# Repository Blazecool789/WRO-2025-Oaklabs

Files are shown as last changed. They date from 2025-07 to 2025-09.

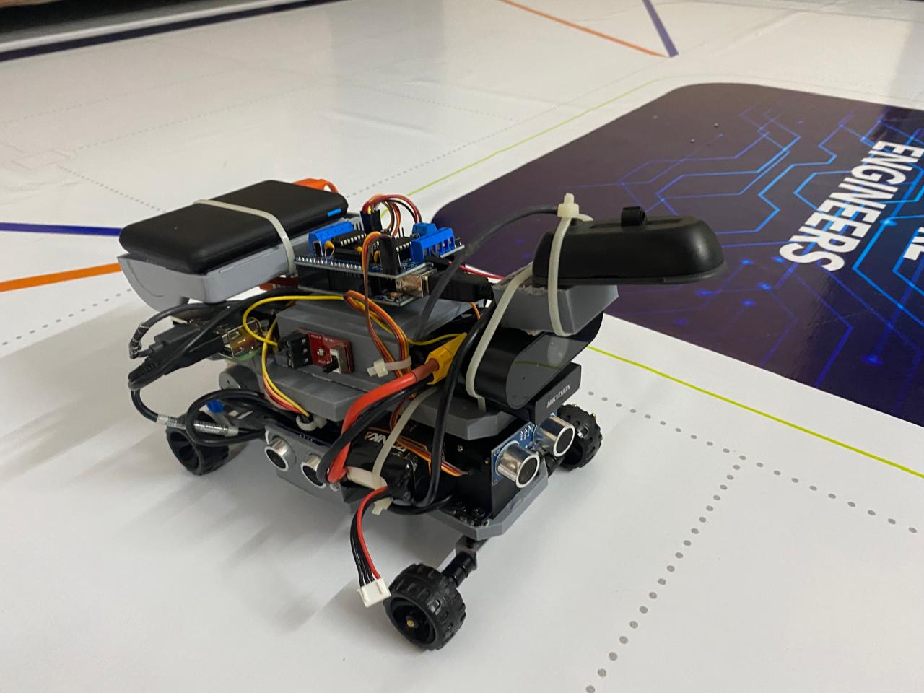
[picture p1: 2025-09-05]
Bot Photos/Top Side View.jpg

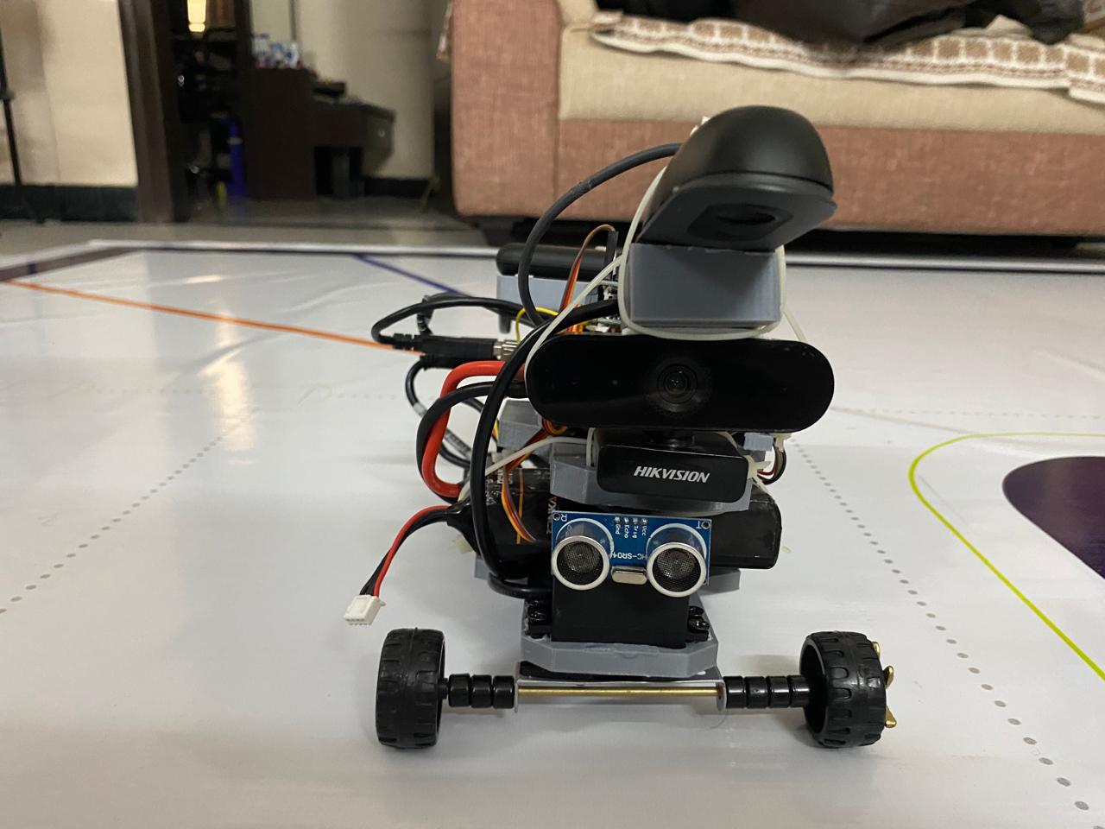
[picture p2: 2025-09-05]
Bot Photos/Front View.jpg

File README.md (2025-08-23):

# Oak-Labs

This repository contains the work of Team Oaklabs, developed for the WRO 2025 Future Engineers competition. Our robot combines simplicity with advanced technical systems to ensure efficiency, reliability, and adaptability across all phases of the challenge.

### Members:
 - Supratiik Koppuravuri

 - Aneesh Kulkarni

 - Krishna Hanumanthu

## Project/bot description :

Our robot is designed around a distributed control system that uses two microcontrollers: an Arduino Uno and a Raspberry Pi 5.

The Arduino Uno handles real-time actuation, low-latency sensor processing, and precise motor control.

The Raspberry Pi 5 performs high-level decision-making, camera-based vision processing, and computationally intensive tasks.

## Table of contents :

Team-photos : Photos of each team member (formal & informal)

Bot-photos : Multiple views of the robot (front, back, left, right, top, bottom)

Diagrams and schemes : Visual representations of system architecture, wiring, and component interconnections

Materials and components : Detailed list of all hardware and electronics used

3D models : CAD designs and animations of the robot build

Reference documents : Reports/manuals covering design decisions and logistics

TeamCode : Complete codebase with explanations for each competition phase

Videos : Demonstration of the robot performing different tasks

## Introduction

Team Oaklabs proudly presents its robot for the World Robot Olympiad 2025 (Future Engineers).

Our design philosophy emphasizes efficiency, precision, and modularity. By distributing responsibilities between the Arduino and Raspberry Pi, the robot executes movements with speed while simultaneously processing complex vision-based tasks.

Highlights of our approach:

Distributed architecture: separates time-critical motor control from computationally heavy tasks.

Sensor fusion: combines ultrasonic data with camera vision for robust navigation.

Adaptive behavior: the robot dynamically switches strategies between obstacle navigation, line-following, and parallel parking.

Deterministic communication protocol: ensures that commands from the Raspberry Pi to the Arduino translate into predictable actions.

Modularity: components can be easily replaced or upgraded, making the system flexible and competition-ready.

By balancing advanced algorithms with practical engineering, Oaklabs has built a robot capable of tackling every stage of the competition with speed, consistency, and adaptability.

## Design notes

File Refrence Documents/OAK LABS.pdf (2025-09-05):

# OAK LABS

# Team No. 1121 Aneesh, Supratiik, & Krishna

# Future engineer’s JOURNAL

# The Team

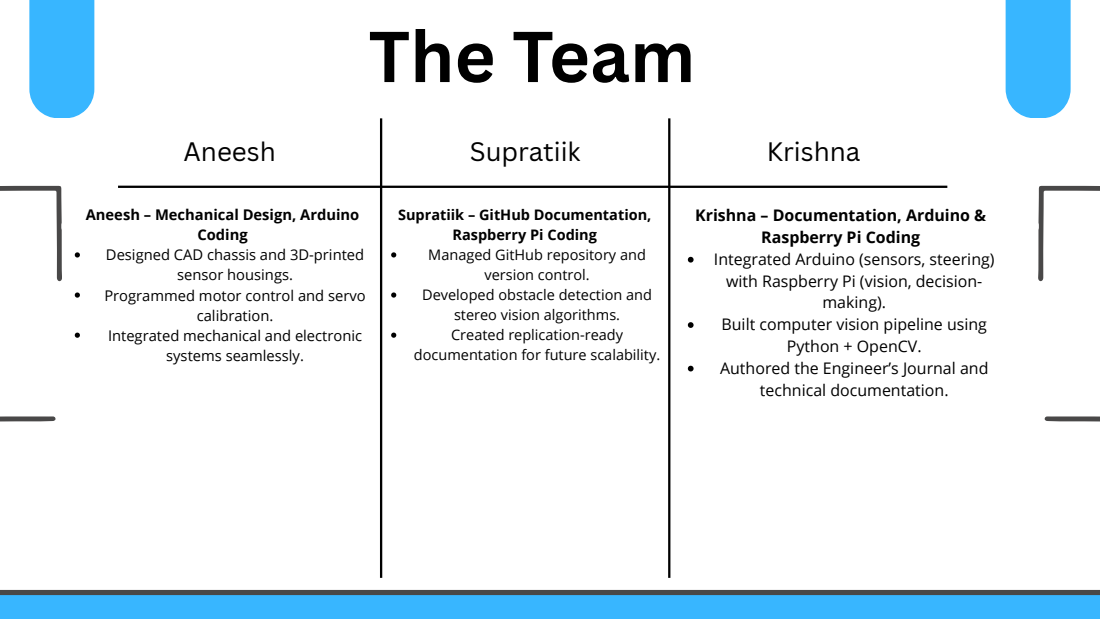
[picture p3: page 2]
Aneesh; Supratiik; Krishna; making).; Python + OpenCV.; Coding; sensor housings.; calibration.

Aneesh – Mechanical Design, Arduino

Supratiik – GitHub Documentation,
Raspberry Pi Coding
Managed GitHub repository and
version control.

Krishna – Documentation, Arduino &

Integrated Arduino (sensors, steering)
with Raspberry Pi (vision, decision-

Designed CAD chassis and 3D-printed

Programmed motor control and servo

Developed obstacle detection and
stereo vision algorithms.
Created replication-ready
documentation for future scalability.

Built computer vision pipeline using

Integrated mechanical and electronic
systems seamlessly.

Authored the Engineer’s Journal and
technical documentation.

# TABLE OF CONTENTS

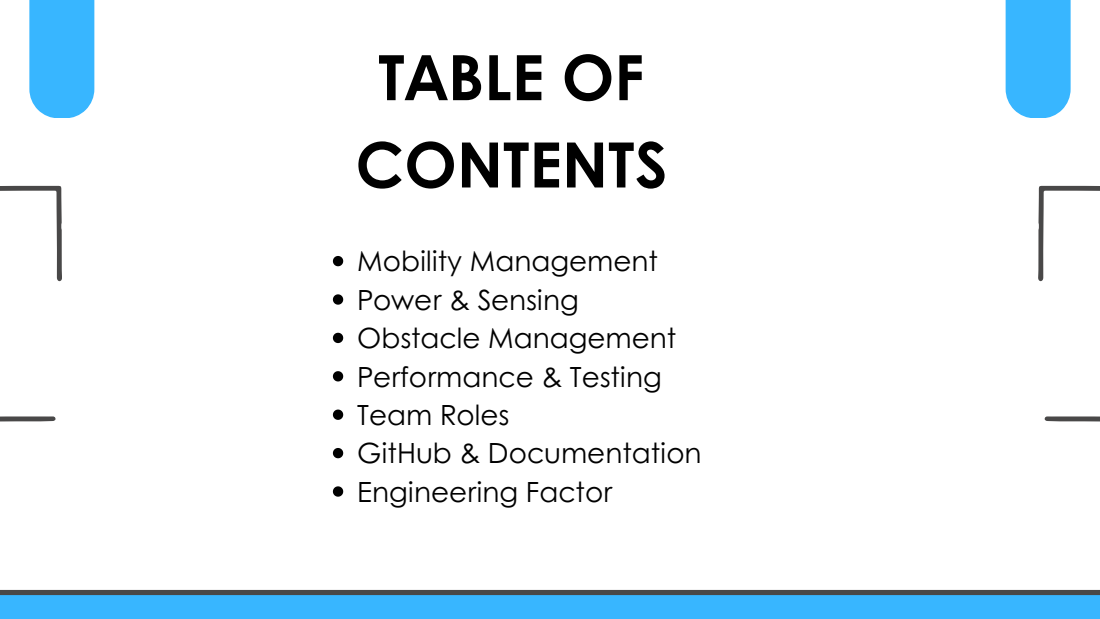
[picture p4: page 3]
Mobility Management Power & Sensing Obstacle Management Performance & Testing Team Roles GitHub & Documentation Engineering Factor

# 1. Mobility Management

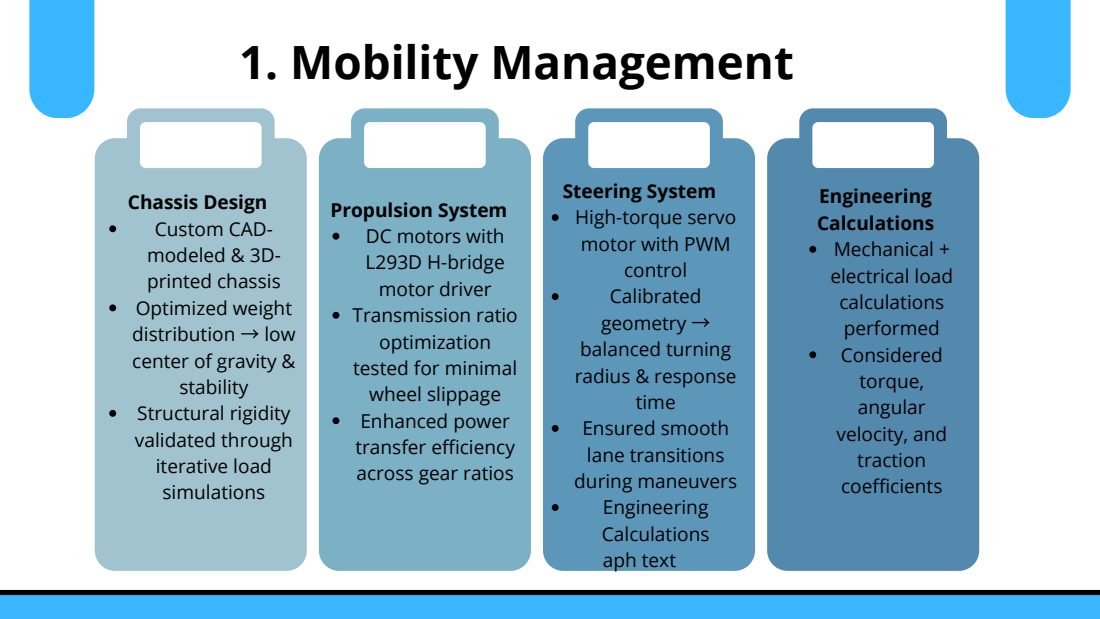
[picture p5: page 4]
Engineering Calculations Mechanical + electrical load calculations performed Considered torque, angular velocity, and traction coefficients

Steering System
High-torque servo
motor with PWM
control
Calibrated
geometry →
balanced turning
radius & response
time
Ensured smooth
lane transitions
during maneuvers
Engineering
Calculations
aph text

Chassis Design
Custom CAD-
modeled & 3D-
printed chassis
Optimized weight
distribution → low
center of gravity &
stability
Structural rigidity
validated through
iterative load
simulations

Propulsion System
DC motors with
L293D H-bridge
motor driver
Transmission ratio
optimization
tested for minimal
wheel slippage
Enhanced power
transfer efficiency
across gear ratios

# 2.POWER & SENSE MANAGMENT

## Power & Sense Management Power Architecture

Dual-source: Li-ion battery for Arduino, power bank for Raspberry Pi. Energy audit ensured stable voltage and prevented brownouts.

## Perception System

Stereo vision with dual webcams for lane detection & sign recognition. Depth estimation improved accuracy in feature extraction.

## Sensor Fusion

HC-SR04 ultrasonic sensor for obstacle ranging. Combined with vision data for reliable detection.

## Wiring & Stability

Structured wiring plan + Bill of Materials (BOM). Capacitor-based decoupling reduced noise and stabilized signals.

# OBSTACLE MANAGEMENT

Vision-Based Detection
Python + OpenCV pipeline for obstacle segmentation
NumPy computations enabled real-time matrix operations Decision-Making Algorithm
Flowchart-based logic converted sensor data into avoidance maneuvers Fusion of vision + ultrasonic inputs for reliable decisions
Safety & Reliability
Failsafe stop protocol triggered on conflicting sensor signals
Priority given to collision prevention over lane-following Ultrasonic Integration
Arduino trigger–echo time-of-flight algorithm for precise ranging Millimeter-scale accuracy achieved during testing
Performance Validation
Avoidance maneuvers maintained lane alignment
System proven robust under multi-variable test scenarios

GitHub Utilization
Repository Structure
/software – Python and Arduino source code
/hardware – CAD models, wiring diagrams, 3D-print files
/docs – Engineer’s Journal, schematics, testing protocols, performance logs /media – Photos, annotated diagrams, demonstration videos
Version Control & Collaboration Git used with descriptive commit messages (e.g., fix, feat, tune)
Frequent commits by all team members demonstrate distributed collaboration
Ensures iterative refinement and traceability of changes
Documentation & Replication README.md includes setup instructions, architectural explanations, and replication guidelines Supports knowledge transfer for future teams

# GITHUB UTILIZATION

Engineering Factor
Custom Architecture & Modularity Integrated off-the-shelf components into a bespoke, scalable system Guided by principles of modularity and expandability
Chassis & Mechanical Design 3D-printed chassis iteratively refined, reducing weight by 20% Maintained structural rigidity while optimizing maneuverability Adjusted mechanical elements to improve transmission efficiency
Electrical & Sensor Optimization Power regulation circuits improved to mitigate instability
Sensor suite designed for maximum field-of-view for lane detection and obstacle avoidance Iterative Engineering Cycle Early prototypes addressed overweight, energy inefficiency, and imbalance
Final design achieved lightweight, reliable, and optimized autonomous platform Demonstrates analysis → prototyping → testing → refinement

# ENGINEERING FACTOR

# THANK YOU

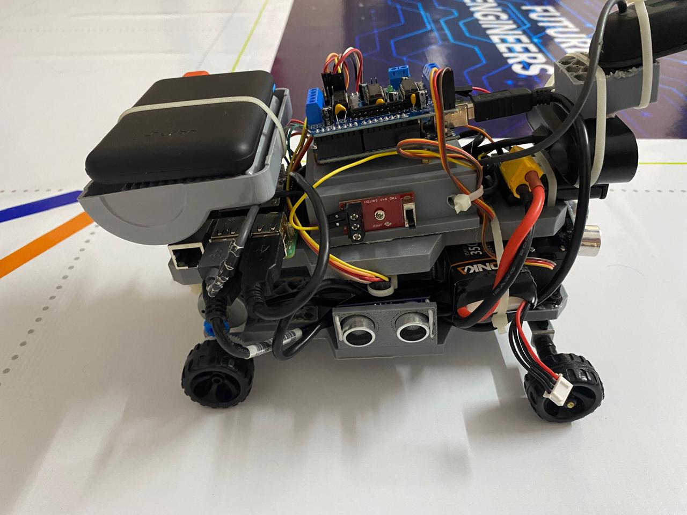
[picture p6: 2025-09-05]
Bot Photos/Side View.jpg

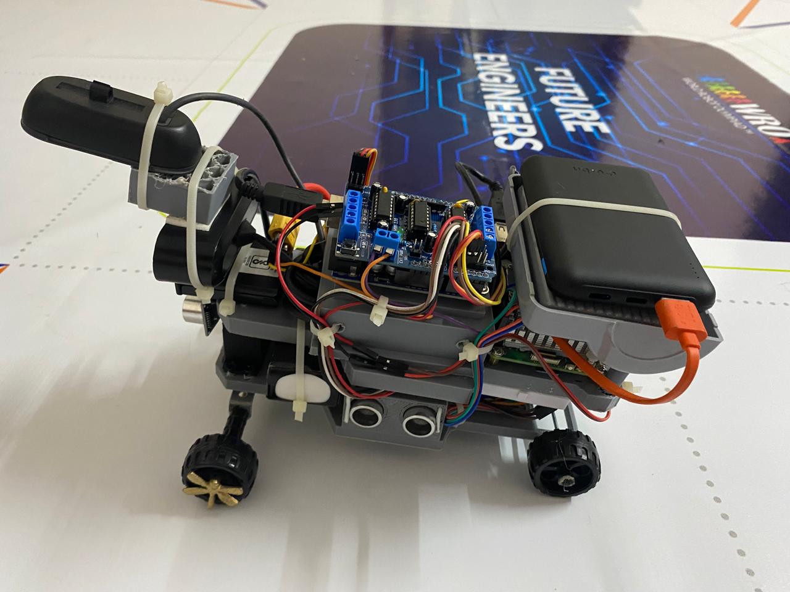
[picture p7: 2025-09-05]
Bot Photos/Other Side View.jpg

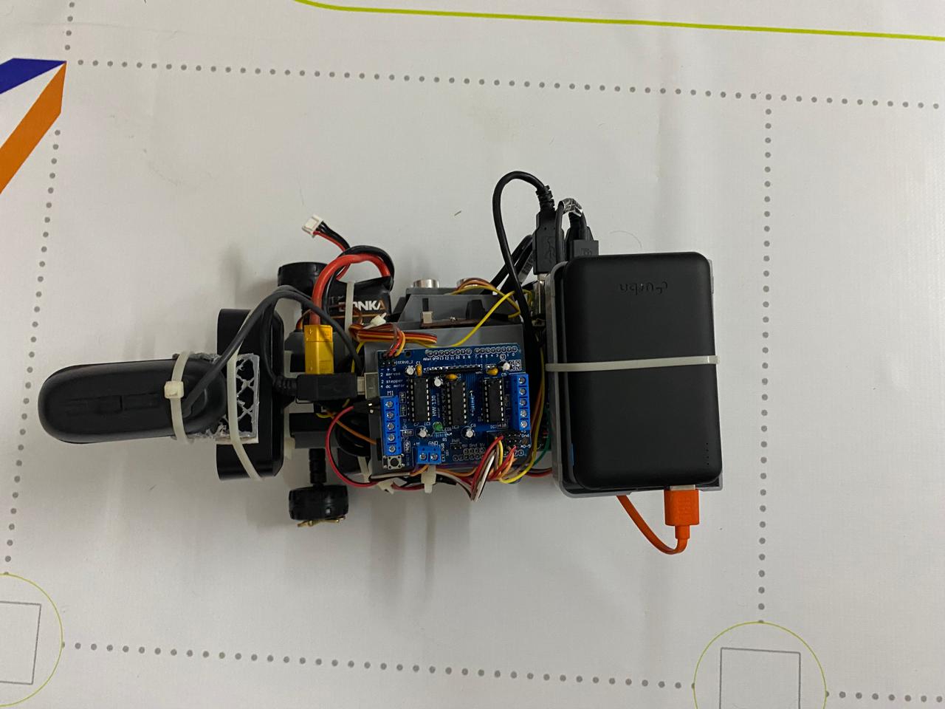
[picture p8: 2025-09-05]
Bot Photos/Top View.jpg

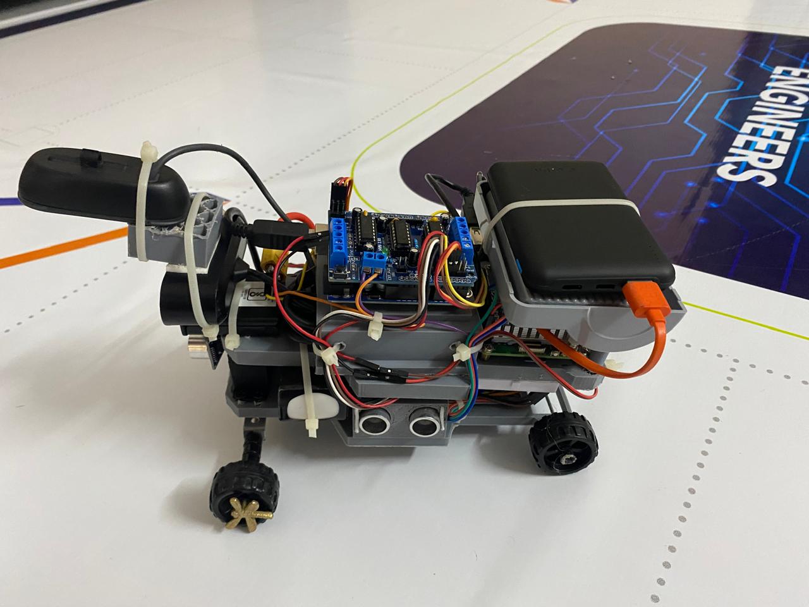
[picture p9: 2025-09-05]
Bot Photos/Top Other Side View.jpg

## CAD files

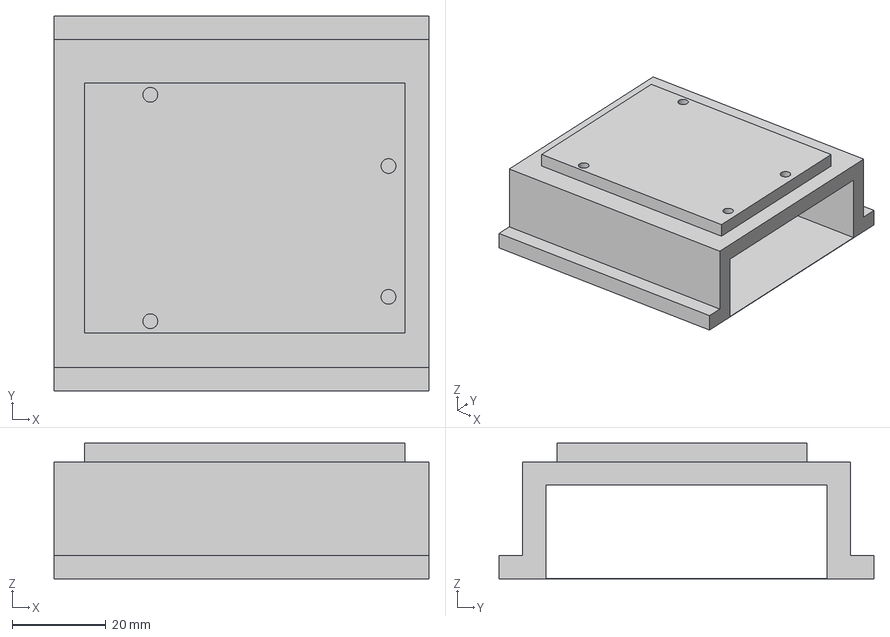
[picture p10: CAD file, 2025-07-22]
3D designs/Arduino Mount/Arduino mount v2.3mf
80.0 x 80.0 x 29.0 mm

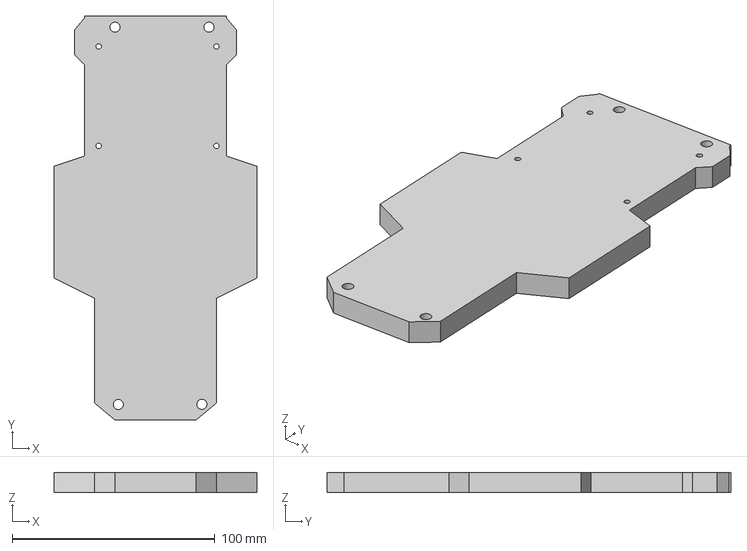
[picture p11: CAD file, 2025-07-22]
3D designs/Baseplate/Baseplate_.3mf
100.0 x 199.0 x 10.0 mm

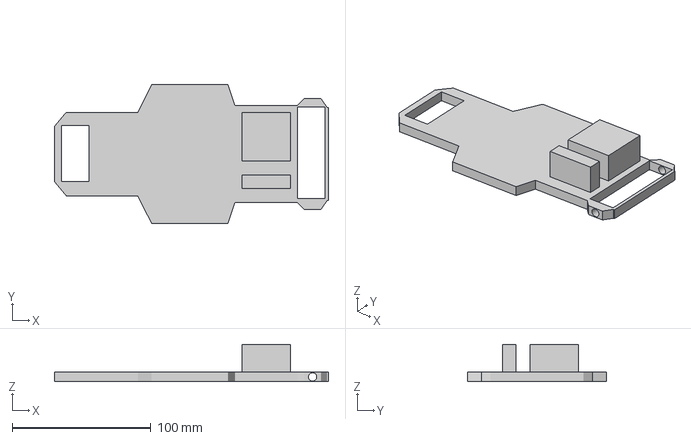
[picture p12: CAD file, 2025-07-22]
3D designs/Bottom Plate/Bottom Plate_.3mf
197.5 x 100.0 x 27.0 mm

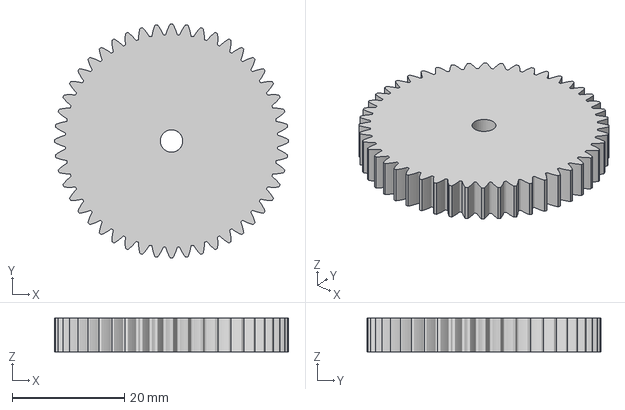
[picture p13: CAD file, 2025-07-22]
3D designs/Gear/Gears v5.3mf
41.7 x 41.7 x 6.00 mm

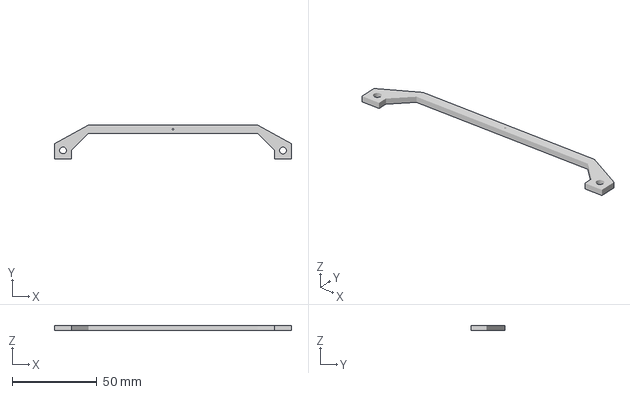
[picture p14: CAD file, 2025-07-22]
3D designs/Steering Actuator/Steering Actuator_.3mf
140.0 x 20.0 x 3.00 mm

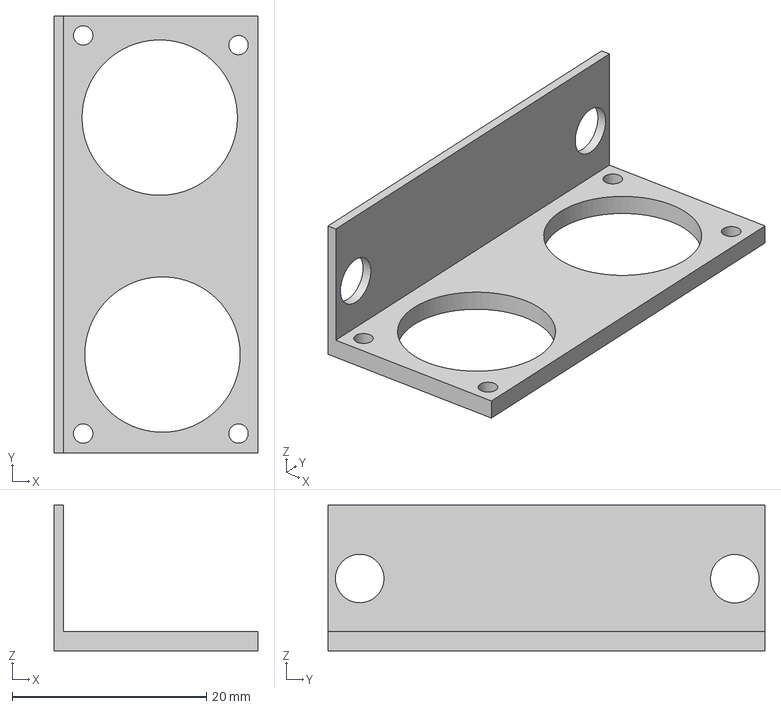
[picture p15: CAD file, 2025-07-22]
3D designs/Ultrasonic Baseplate/Ultrasonic Sensor Baseplate_.3mf
21.0 x 45.0 x 15.0 mm

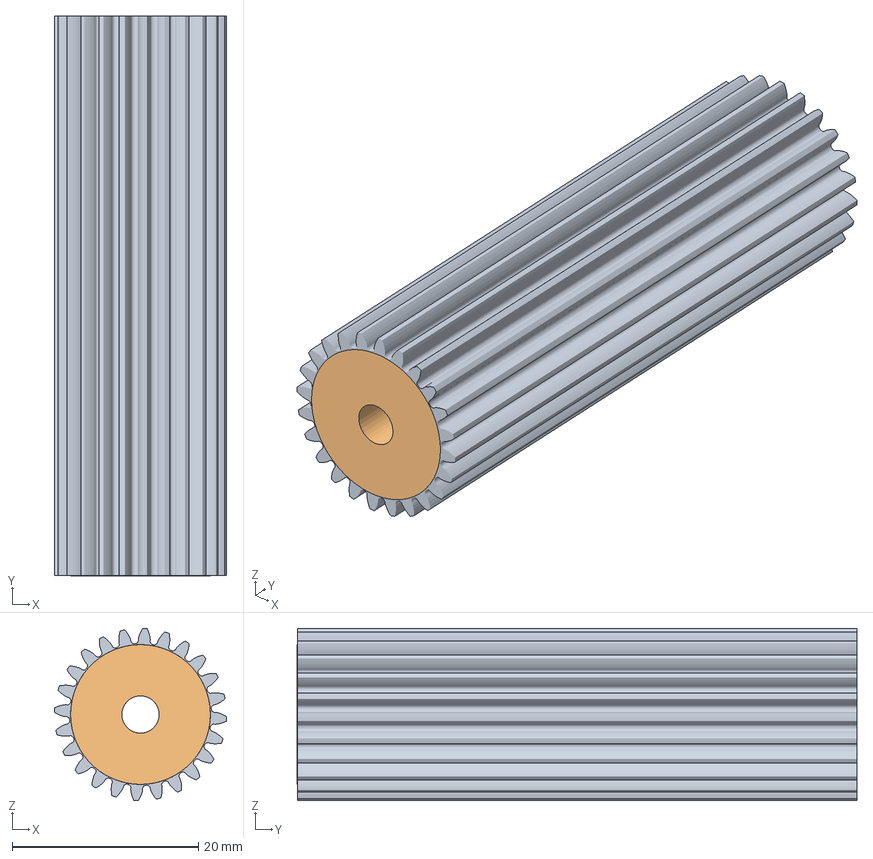
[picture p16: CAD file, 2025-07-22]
3D designs/Gear/Back Gear v3.3mf
18.5 x 60.0 x 18.5 mm

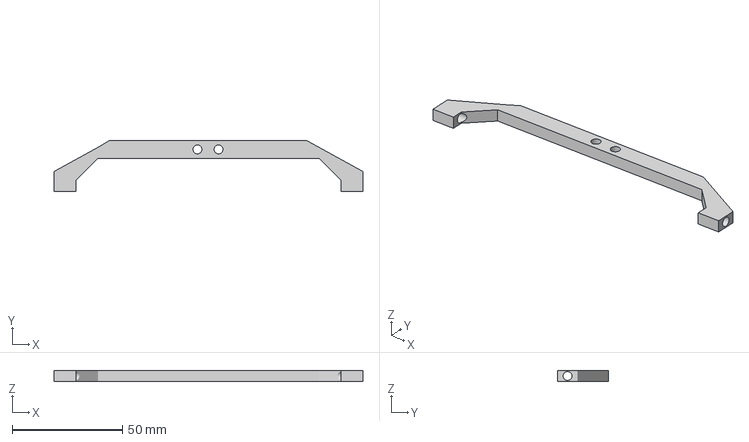
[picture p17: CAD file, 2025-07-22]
3D designs/Steering Actuator/Steering Actuator v8.3mf
140.0 x 23.0 x 5.00 mm

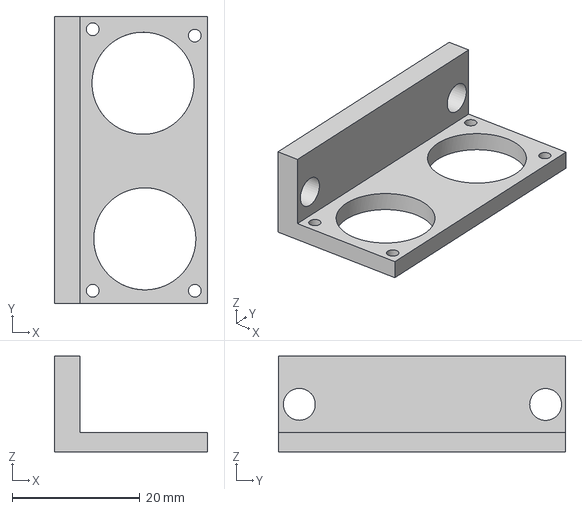
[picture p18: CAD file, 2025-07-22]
3D designs/Ultrasonic Baseplate/Ultrasonic Sensor Baseplate v4.3mf
24.0 x 45.0 x 15.0 mm

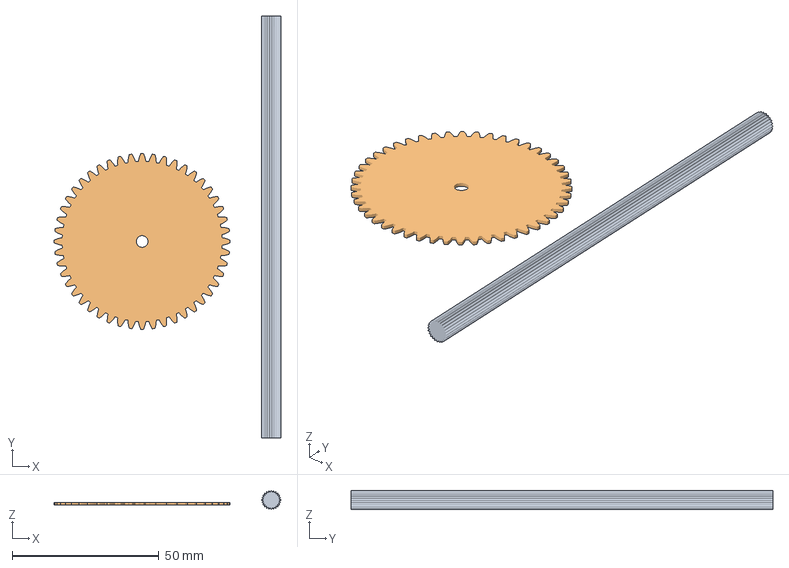
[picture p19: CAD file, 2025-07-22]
3D designs/Gear/Gears_.3mf
77.3 x 144.0 x 6.50 mm

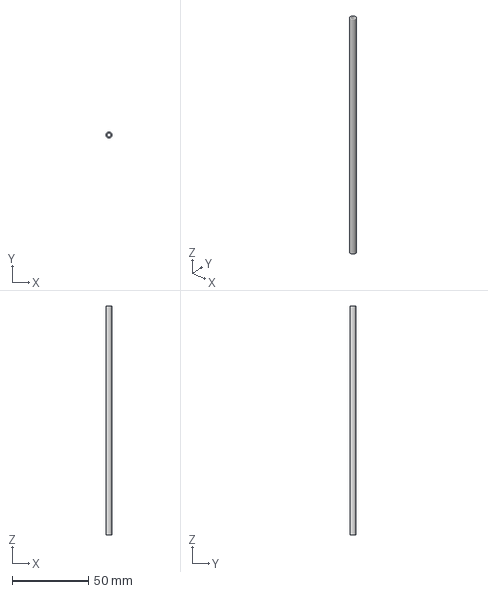
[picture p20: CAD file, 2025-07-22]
3D designs/Steering Actuator/Height Standoff v1.3mf
4.00 x 4.00 x 150.0 mm

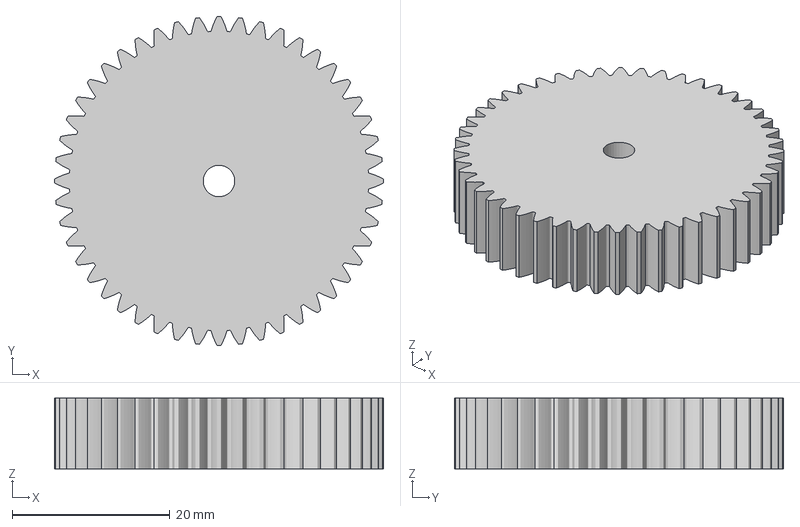
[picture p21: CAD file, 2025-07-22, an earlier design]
3D designs/Gear/Gears v4.3mf
41.7 x 41.7 x 9.00 mm

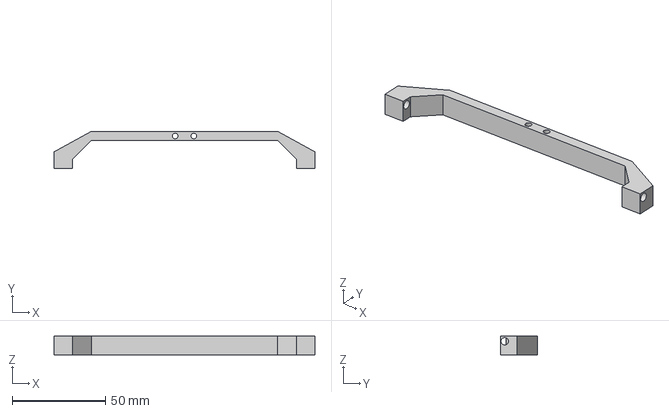
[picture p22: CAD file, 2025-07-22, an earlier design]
3D designs/Steering Actuator/Steering Actuator v5.3mf
140.0 x 20.0 x 10.0 mm

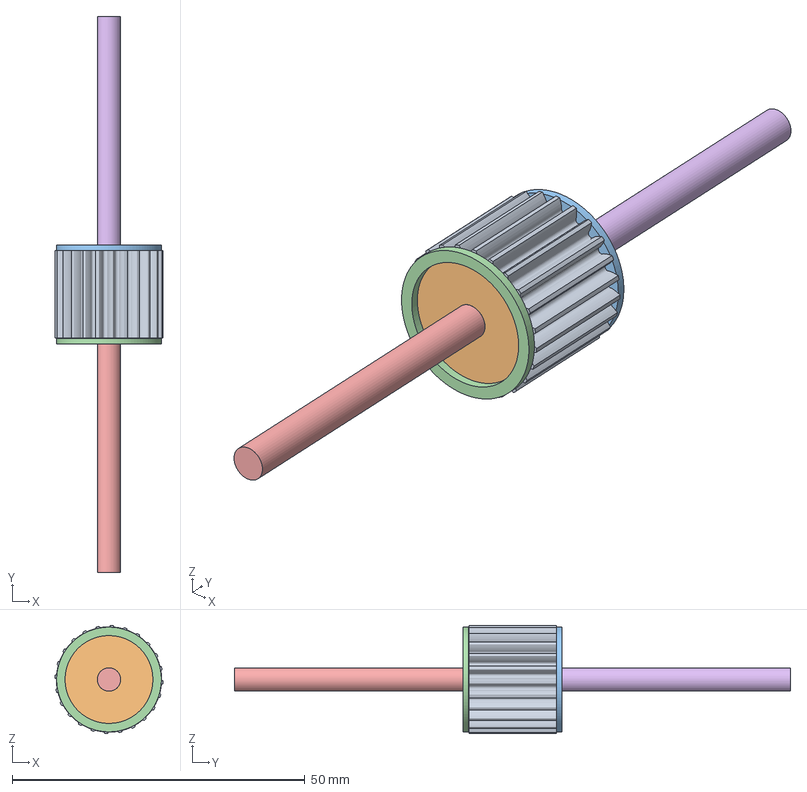
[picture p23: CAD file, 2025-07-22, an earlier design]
3D designs/Gear/Back Gear v2.3mf
18.5 x 95.0 x 18.5 mm

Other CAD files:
3D designs/Steering Actuator/Steering Actuator v6.3mf
3D designs/Gear/Back Gear v1.3mf
3D designs/Ultrasonic Baseplate/Ultrasonic Sensor Baseplate v4.f3d

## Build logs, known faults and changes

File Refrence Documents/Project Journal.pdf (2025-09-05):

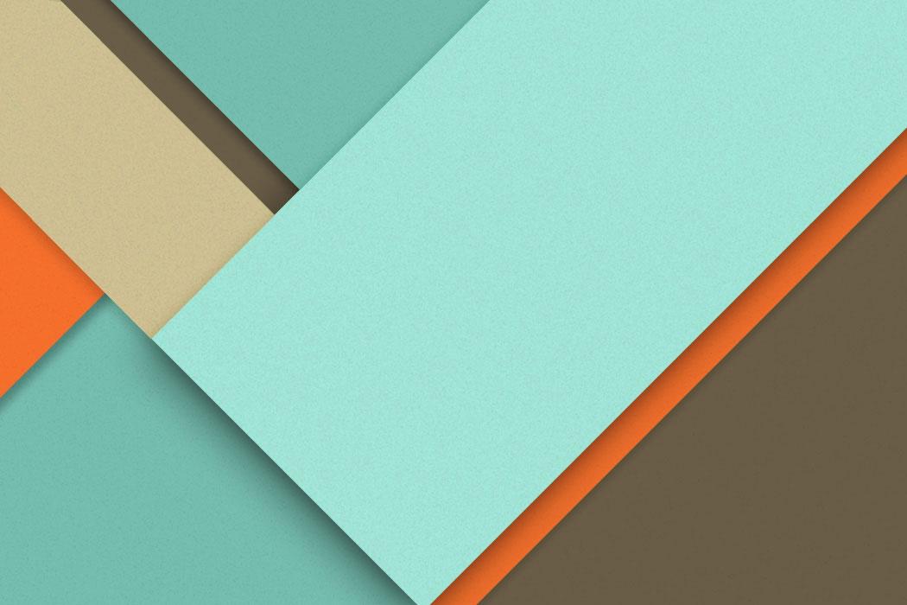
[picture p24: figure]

# Oak-Labs Documentation

### Created by: The Oak-Labs Team For the: World Robotics Olympiad (WRO) Future Engineers 2025

──────────────────────────────────

# Table of Content

### 1. Mobility Management

a. Driving System - Back wheel drive, front wheel steer
b. Steering Mechanisms
c. Components Used

### 2. Engineering Principles

a. Mechanical Engineering Principles
i. Kinematics - 2:1 gear ratio, copy paste ii. Load Distribution and Torque
b. Electrical Engineering Principles
i. Pulse Width Modulation (PWM)
c. Software Engineering Principles
i. Sensor integration & Decision Making
d. Systems Engineering Principles
i. Systems Integration

### 3. Iteration Manual

a. First Iteration
b. Second Iteration
c. Finalized Iteration

### 4. Power and Sense Management

a. Power Management
i. Power Source
b. Sensors

# Mobility Management

# Driving System

### 1.1 RS-365PH Dual-Shaft Motor

The RS-365PH motor powers both rear wheels through a single axle drive, connected by a 2:1 gear ratio gear system. This means that both rear wheels rotate at the same speed, but with twice the torque and half the speed compared to the motor’s direct output. The dual-shaft configuration allows stable gear mounting and better torque transfer to the axle.

RS-365PH Motor Specifications:

- Operating voltage: 6V to 24V (DEPENDS ON MODEL)
- No-load speed: ~4000 RPM at 9V (DEPENDS ON MODEL)
- Current draw: 70–250 mA at no load, significantly higher under load

The motor is controlled by PWM signals from the Arduino Uno, which regulate the speed of the rear wheels. The motor driver manages the power supply and controls motor direction.

How It Works:

- Forward movement: The RS-365PH drives the rear wheels through the single axle. With the 2:1 gear ratio, the wheels spin at half the motor’s output speed but with increased torque, giving smoother acceleration and stronger pulling power.
- Backward movement: The motor reverses, causing both rear wheels to rotate in the opposite direction, moving the bot backward.

Since there is no differential, both rear wheels are always locked to rotate at the same speed. This setup provides reliable forward and backward motion, but turning relies heavily on the front-wheel steering system.

### 1.2 Single Axle and 2:1 Gear Ratio

The 2:1 gear ratio ensures that the rear wheels receive more torque for stronger pushing power, while still rotating at the same speed. This simplifies the drivetrain but makes the bot fully reliant on the front servo steering for turning.

# Steering System

### 1.3 Tower Pro MG995 Servo Motor

The steering system is powered by a Tower Pro MG995 high-torque servo motor, which controls the angle of the front two wheels. This servo provides reliable torque and durable performance compared to smaller micro servos, making it well-suited for steering applications in the bot.

Tower Pro MG995 Servo Specifications:

- Operating voltage: 4.8V – 7.2V
- Torque: ~10 kg·cm at 6V
- Speed: ~0.20s/60° at 6V
- Control: PWM signal from Arduino Uno

The MG995 is a metal-geared, high-torque servo with a rotation range of about 0° to 180°. In this bot, it controls the front wheels within a restricted range of angles to steer left or right, ensuring both stability and precision.

How It Works:

- Left turn: The servo shifts the front wheels left by rotating to a negative steering angle.
- Right turn: The servo shifts the front wheels right by rotating to a positive steering angle.
- Straight movement: When the servo is in its neutral (centered) position, the front wheels remain aligned forward, enabling straight movement.

Control Logic:
The robot’s Camera 1 is managed by the Raspberry Pi, which performs color-based detection. When a condition is triggered (e.g., detecting green for left or red for right), the Pi sends a variable to the Arduino Uno. The Arduino interprets this variable and outputs the corresponding PWM signal to the MG995 servo, adjusting the steering angle of the front wheels accordingly.

# Components

Component | Function | Power Requirements
RS-365PH Motor | Drives the two rear wheels for movement (forward/back ward). | 6V - 24V
Single Axle Drive | Allows rear wheels to rotate at different speeds during turns. | N/A (Mechanical)
Tower Pro MG995 Servo | Controls the angle of the front wheels for steering. | 4.8V - 7.2V
Motor Driver | Controls the DC motor's speed and direction. | Motor Side: 11.1V; Logic is 5V

# Engineering Principles

# Mechanical Engineering Principles

### 1.1 Single Axle Drive with 1:1 Gear Ratio (Kinematics)

The propulsion system is based on a single axle drive with a 1:1 gear ratio, ensuring that both rear wheels rotate at the same speed. This setup simplifies the kinematics of motion, as speed and direction are uniformly applied across the axle. With this arrangement, the bot is optimized for consistent, straight-line motion.

- Straight-Line Motion: Since the rear wheels rotate at equal speeds, forward and backward movement is stable and predictable. The 1:1 gear ratio prevents slippage between wheels, maintaining uniform motion.
- Turning Radius: Unlike a differential system, the bot cannot vary the rear wheel speeds independently. As a result, the turning radius is entirely governed by the front-wheel steering, controlled by the MG995 servo motor. A greater steering angle produces a tighter turning radius, which is essential for maneuvering around obstacles or sharp corners on the track.

### 1.2 Load Distribution and Torque (Statics and Dynamics)

In this design, torque is generated by the RS-366PH dual-shaft motor and transmitted to the rear axle, while stability depends on effective load distribution.

- Torque and Traction: The RS-366PH provides sufficient torque to drive the bot forward. Proper weight distribution ensures that the rear wheels maintain traction with the track, preventing slippage and maximizing efficiency.
- Stability During Turns: Turning dynamics are influenced by the bot’s center of mass, wheel placement, and weight distribution. The Tower Pro MG995 servo, with its high-torque capability, provides the necessary force to adjust the steering angle without compromising stability during sharp turns.

## Electrical Engineering Principles

### 2.1 Pulse Width Modulation (PWM) for Speed and Steering Control

Both the RS-366PH motor and the MG995 servo are controlled using Pulse Width Modulation (PWM) signals, which regulate power delivery by varying the duty cycle of electrical pulses.

- Motor Speed Regulation: By modulating PWM signals sent to the RS-366PH motor driver, the bot’s propulsion speed can be dynamically adjusted. This allows acceleration on straight tracks and deceleration when approaching obstacles or curves, ensuring both efficiency and safety.
- Servo Angle Control: The MG995 servo receives PWM signals to control its angular position. Depending on input from the vision system, the servo adjusts the front-wheel angle—for example, steering left when detecting green or right when detecting red—thereby guiding the bot accurately through the track.

## Software Engineering Principles

### 3.1 Sensor Data Integration and Decision-Making (Pi–Arduino Communication)

The navigation system relies on real-time sensor fusion between the Raspberry Pi and Arduino Uno. Camera 1, controlled by the Pi, performs color detection to identify track markers and blocks. When the Pi detects a specific condition—such as an orange block—it sends a variable through serial communication to the Arduino. The Arduino then executes the corresponding action by controlling the RS-366PH dual-shaft motor for propulsion and the MG995 servo for steering.

- Obstacle Detection and Response: Ultrasonic sensors mounted on the left and right sides measure distances to nearby obstacles. If an obstacle is within a set threshold, the Arduino triggers corrective steering adjustments using the MG995 servo to avoid collisions.
- Color-Based Commands: The Pi translates visual data into commands (e.g., 'R' for red → right turn, 'L' for green → left turn, 'O' for orange → special maneuver). These commands are transmitted via serial to the Arduino, which executes them after checking a cooldown timer to prevent rapid conflicting inputs.

- Data Filtering: To ensure stability, the system uses timed checks and ignores redundant or noisy signals. This helps maintain smooth control, especially on tracks with frequent color markers or environmental disturbances.

### 3.2 Feedback Control System

The bot employs a closed-loop feedback control strategy to constantly adjust its motion based on sensor inputs. This ensures reliable navigation and adaptability to dynamic environments.

- Closed-Loop Control: Sensor readings (ultrasonic distances, Pi color detection) are continuously fed into the Arduino’s control loop. For example, if the ultrasonic sensor detects a nearby obstacle, the bot slows down or adjusts steering until the path is clear.
- Command Execution: When the Pi detects an orange block and sends the 'O' command, the Arduino interprets this and modifies the servo/motor behavior accordingly. Cooldown logic ensures that each action completes before another command is executed, preventing instability.

## Systems Engineering Principles

### 5.1 Systems Integration

Systems engineering principles ensure that power delivery, motor control, sensor feedback, and decision-making operate as a unified system.

- Component Interfacing: Reliable communication between the Raspberry Pi, Arduino Uno, ultrasonic sensors, cameras, MG995 servo, and RS-366PH motor is critical. The Pi handles vision-based color detection and transmits commands to the Arduino, which in turn manages actuation through PWM signals. Continuous data exchange between these subsystems ensures smooth navigation.
- Modularity: Each subsystem—propulsion (RS-366PH motor), steering (MG995 servo), sensing (cameras + ultrasonics), and power regulation (buck converters)—is developed as a modular unit. This approach simplifies debugging, testing, and future upgrades, as improvements can be made to one subsystem without disrupting the functionality of the entire bot.

## Power and Sense Management

## Power

### 1.1 Power Source

The main power source for the bot is a 3S 11.1V LiPo battery. This battery provides the necessary power to all sensors and the Arduino Uno, which acts as the main controller for the system. LiPo batteries are known for their high energy density, providing ample power for mobile robotic systems.

Battery specs:

- Voltage: 11.1V
- Current: 800mAH
- Configuration: 3 cells in series (3S)
- Battery type: LiPo (Lithium Polymer)

## Sensors

This section outlines all the sensors integrated into the 4-wheel bot, their functions, and power requirements.

### 2.1 Ultrasonic Sensors (HC-SR04)

Three HC-SR04 ultrasonic sensors are mounted on the bot for obstacle detection and distance measurement.

Power Specs:

- Operating Voltage: 5V DC
- Operating Current: 15mA
- Working Frequency: 40kHz

Sensor Roles:

- Front Ultrasonic Sensor: Detects the distance to obstacles directly ahead, preventing frontal collisions.
- Left Ultrasonic Sensor: Monitors proximity to obstacles on the left side, ensuring the bot does not drift too close to barriers.
- Right Ultrasonic Sensor: Tracks distance on the right side, preventing collisions from that direction.

These sensors provide essential data for collision avoidance and path planning.

### 2.3 Webcam (Generic USB Camera)

A generic USB webcam is used for vision-based navigation and obstacle recognition. Unlike ultrasonic sensors, the webcam processes visual data to identify colored markers or objects along the track.

Power Specs:

- Operating Voltage: 5V DC (via USB)
- Current: ~120–200mA (depending on model)

Sensor Roles:

- The webcam captures live video and streams it to the Raspberry Pi, where image processing algorithms identify color-coded obstacles.
- Red marker/object: Signals the bot to turn right.
- Green marker/object: Signals the bot to turn left.

The camera, in coordination with the Raspberry Pi and Arduino, enables real-time decision-making for navigation and obstacle avoidance.

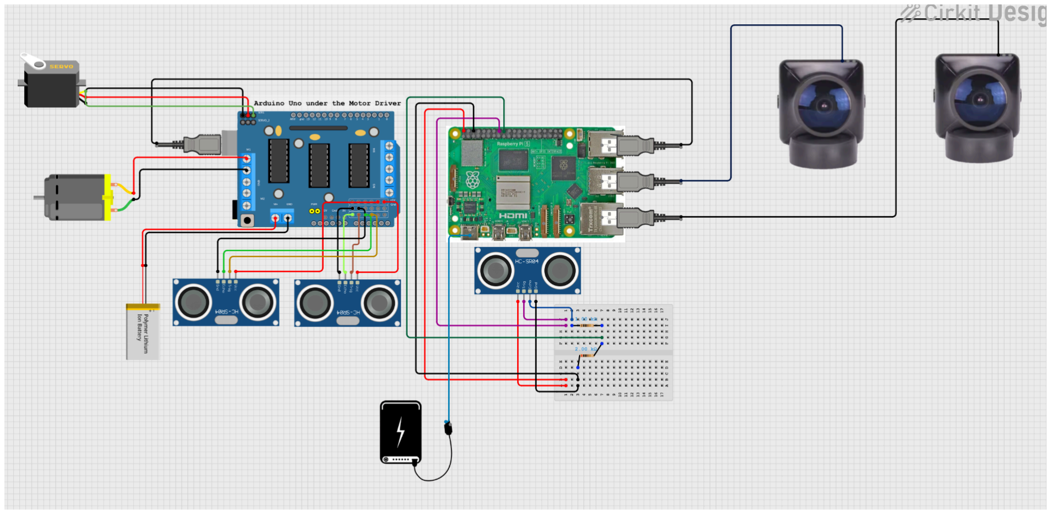
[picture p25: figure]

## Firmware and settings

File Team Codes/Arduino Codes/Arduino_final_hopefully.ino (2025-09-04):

#include <Servo.h>
#include <AFMotor.h>

AF_DCMotor motor1(1);
int Start = 250;
int Stop = 0;

Servo myServo;
const int servoPin = 10;
int start_pos = 90;
int cur_pos = 0;    
int new_pos = 0;
int angle = 30;

const int leftTrigPin = A1;
const int leftEchoPin = A0;
const int rightTrigPin = A3;
const int rightEchoPin = A2;
// Timing for obstacle checks
unsigned long lastObstacleCheck = 0;
const unsigned long obstacleInterval = 200; // ms
const int obstacleThreshold = 20;


// Cooldown tracking
unsigned long lastCommandTime = 0;
const unsigned long commandCooldown = 500; // 5 seconds

int baud_rate = 9600; //115200
char c = ' ';
char u = ' ';

int park_complete = 0;

void go_forward()
{
  Serial.print("\nForward - m1, m2, m3, m4: ON"); 
  motor1.run(FORWARD);
  motor1.setSpeed(Start);  
  delay(10);
}

void go_backward()
{
  Serial.print("\nBackward - m1, m2, m3, m4: ON"); 
  motor1.run(BACKWARD);
  motor1.setSpeed(Start);  
  delay(140);
}

void stop_rover()
{
  Serial.print("\nNo move - m1, m2, m3, m4: OFF"); 
  motor1.setSpeed(Stop);
  motor1.run(RELEASE);
}


int read_left_sensor()
{
  long left_duration;
  int left_sense_distance;
  digitalWrite(leftTrigPin, LOW);
  delayMicroseconds(2);
  digitalWrite(leftTrigPin, HIGH);
  delayMicroseconds(10);
  digitalWrite(leftTrigPin, LOW);
  left_duration = pulseIn(leftEchoPin, HIGH);
  left_sense_distance = left_duration * 0.034 / 2;
  Serial.print("\nLeft Distance: ");
  Serial.println(left_sense_distance);
  return left_sense_distance;
}

int read_right_sensor()
{
  long right_duration;
  int right_sense_distance;
  digitalWrite(rightTrigPin, LOW);
  delayMicroseconds(2);
  digitalWrite(rightTrigPin, HIGH);
  delayMicroseconds(10);
  digitalWrite(rightTrigPin, LOW);
  right_duration = pulseIn(rightEchoPin, HIGH);
  right_sense_distance = right_duration * 0.034 / 2;
  Serial.print("\nRight Distance: ");
  Serial.println(right_sense_distance);
  return right_sense_distance;
}

void checkObstacles() 
{
  long leftDistance = read_left_sensor(); //measureDistance(leftTrigPin, leftEchoPin);
  long rightDistance = read_right_sensor(); //measureDistance(rightTrigPin, rightEchoPin);
  
  if (leftDistance > 0 && leftDistance < obstacleThreshold) 
  {
    Serial.print("\nLeft Obstacle detected..");
    stop_rover();
    delay(1000);
    turnRight(30);
    go_forward();
    delay(1000);
    turnStraight();
  }
  
  if (rightDistance > 0 && rightDistance < obstacleThreshold) 
  {
    Serial.print("\nRight Obstacle detected..");
    stop_rover();
    delay(1000);
    turnLeft(30);
    go_forward();
    delay(1000);
    turnStraight();
  }
}

void turnRight(int degrees) 
{
  int r=0;
  Serial.print("\n\nReceived char 'R'.");
  delay(100);
  cur_pos = myServo.read();
  Serial.print("\nCurrent Servo Position: ");
  Serial.println(cur_pos);
  new_pos = cur_pos + angle;
  for (r=cur_pos; r < new_pos;)
  {
    myServo.write(r);
    r+=2;
    delay(20);
  }
  delay(15);
  cur_pos = myServo.read();
  Serial.print("\nCurrent Servo Position: ");
  Serial.println(cur_pos);
  delay(15);
}

void turnLeft(int degrees) 
{
  int l=0;
  Serial.print("\n\nReceived char 'L'.");
  delay(100);
  cur_pos = myServo.read();
  Serial.print("\nCurrent Servo Position: ");
  Serial.println(cur_pos);
  new_pos = cur_pos - angle;
  for (l=cur_pos; l >= new_pos;)
  {
    myServo.write(l);
    l-=2;
    delay(20);
  }
  delay(15);
  cur_pos = myServo.read();
  Serial.print("\nCurrent Servo Position: ");
  Serial.println(cur_pos);
  delay(15);
}

void turnStraight() 
{
  Serial.print("\n\nMake Straight.");
  delay(100);
  cur_pos = myServo.read();
  Serial.print("\nCurrent Servo Position: ");
  Serial.println(cur_pos);
  new_pos = start_pos;
  myServo.write(new_pos);
  delay(15);
  cur_pos = myServo.read();
  Serial.print("\nCurrent Servo Position: ");
  Serial.println(cur_pos);
  delay(15);
}
void parallelPark() 
{
  Serial.println("Starting parallel parking");
  stop_rover();
  turnRight(angle);
  delay(100);
  go_backward();
  delay(1000);
  stop_rover();
  turnLeft(angle);
  delay(100);
  go_forward();
  delay(1000);
  stop_rover();
  turnStraight();
  park_complete = 1;
  Serial.println("Parking complete");
}


void setup() 
{
  Serial.begin(baud_rate);
  Serial.println("\n\nRover started..");

  myServo.attach(servoPin);
  delay(10);
  myServo.write(start_pos);
  delay(100);
  cur_pos = myServo.read();
  Serial.print("\nCurrent Servo Position: ");
  Serial.println(cur_pos);
  delay(500);
  
  pinMode(leftTrigPin, OUTPUT);
  pinMode(leftEchoPin, INPUT);
  pinMode(rightTrigPin, OUTPUT);
  pinMode(rightEchoPin, INPUT);

  park_complete = 0;

  Serial.println("Ready. Send commands from Raspberry Pi.");
}

void loop() 
 {
  if (park_complete == 0)
  {
    go_forward();
  }
  else
  {
    stop_rover();
  }
  
  // Check serial instantly, no blocking
  if (Serial.available() > 0) 
  {
    c = Serial.read();

    // Ignore whitespace/newline characters
    if (c == '\n' || c == '\r' || c == ' ') return;

    // Check cooldown
    if (millis() - lastCommandTime >= commandCooldown) 
    {
      lastCommandTime = millis(); // Reset cooldown
      Serial.print("Command accepted: ");
      Serial.println(c);

      if (c == 'S') 
      {
        Serial.println("\n\nStart Rover..");
        turnStraight();
        go_forward();
        park_complete = 0;
      } 
      else if (c == 'R') // Turn Right
      {
        turnRight(angle);
        go_forward();
        delay(1000);
        // turnStraight();
      } 
      
      else if (c == 'L') // Turn Left
      {
        turnLeft(angle);   
        go_forward();
        delay(1000);  
        // turnStraight(); 
      } 

      else if (c == 'P') // Parallel Parking
      {
        parallelPark();
      }

      else if (c == 'F') // Fail Safe for obstacles
      {
        stop_rover();
        go_backward();
        delay(1000);
        stop_rover();
        while (1)
        {
          u = Serial.read();
          if (u == 'L')
          {
            turnLeft(angle);
            go_forward();
            delay(1000);  
            turnStraight();
            break;
          }
          else if (u == 'R')
          {
            turnRight(angle);
            go_forward();
            delay(1000);
            turnStraight();
            break;
          }
          delay(100);
        }
      }
        
      else 
      {
        go_forward();
      }
    } 
    else 
    {
      Serial.println("Command ignored - cooldown active");
      // Flush remaining serial input
      while (Serial.available() > 0) Serial.read();
    }
  }
  // Check obstacles on a timed schedule (non-blocking)
  unsigned long currentMillis = millis();
  if (currentMillis - lastObstacleCheck >= obstacleInterval) 
  {
    Serial.print("\nChecking Obstacle..");
    delay(10);
    lastObstacleCheck = currentMillis;
    checkObstacles();
  }
}

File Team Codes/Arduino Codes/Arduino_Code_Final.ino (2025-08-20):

#include <Servo.h>

const int servoPin = 10;
const int motorPin1 = 12;
const int motorPin2 = 13;
const int enablePin = 5;

const int leftTrigPin = A2;
const int leftEchoPin = A3;
const int rightTrigPin = A0;
const int rightEchoPin = A1;

const int obstacleThreshold = 15;

Servo myServo;
int currentServoPosition = 90;

// Timing for obstacle checks
unsigned long lastObstacleCheck = 0;
const unsigned long obstacleInterval = 200; // ms

// Cooldown tracking
unsigned long lastCommandTime = 0;
const unsigned long commandCooldown = 5000; // 5 seconds

void setup() {
  Serial.begin(115200);

  myServo.attach(servoPin);
  myServo.write(currentServoPosition);
  
  pinMode(motorPin1, OUTPUT);
  pinMode(motorPin2, OUTPUT);
  pinMode(enablePin, OUTPUT);
  digitalWrite(enablePin, HIGH);
  
  pinMode(leftTrigPin, OUTPUT);
  pinMode(leftEchoPin, INPUT);
  pinMode(rightTrigPin, OUTPUT);
  pinMode(rightEchoPin, INPUT);

  Serial.println("Ready. Send commands from Raspberry Pi.");
}

void loop() {
  // Check serial instantly, no blocking
  if (Serial.available() > 0) {
    char c = Serial.read();

    // Ignore whitespace/newline characters
    if (c == '\n' || c == '\r' || c == ' ') return;

    // Check cooldown
    if (millis() - lastCommandTime >= commandCooldown) {
      lastCommandTime = millis(); // Reset cooldown
      Serial.print("Command accepted: ");
      Serial.println(c);

      if (c == 'B') {
        Serial.println("B received");
      } 
      else if (c == 'R') {
        Serial.println("R received");
        turnServoRelative(50);
        delay(2);
        turnServoRelative(-50);
        
      } 
      else if (c == 'L') {
        Serial.println("L received");
        turnServoRelative(-50);
        delay(2);
        turnServoRelative(50);
        
      } 
      else {
        executeCommand(c);
      }
    } 
    else {
      Serial.println("Command ignored - cooldown active");
      // Flush remaining serial input
      while (Serial.available() > 0) Serial.read();
    }
  }

  // Check obstacles on a timed schedule (non-blocking)
  unsigned long currentMillis = millis();
  if (currentMillis - lastObstacleCheck >= obstacleInterval) {
    lastObstacleCheck = currentMillis;
    checkObstacles();
  }
}

long measureDistance(int trigPin, int echoPin) {
  digitalWrite(trigPin, LOW);
  delayMicroseconds(2);
  
  digitalWrite(trigPin, HIGH);
  delayMicroseconds(10);
  digitalWrite(trigPin, LOW);
  
  long duration = pulseIn(echoPin, HIGH, 20000); // 20ms timeout
  if (duration == 0) return -1; // No reading
  return duration * 0.034 / 2;
}

void checkObstacles() {
  long leftDistance = measureDistance(leftTrigPin, leftEchoPin);
  long rightDistance = measureDistance(rightTrigPin, rightEchoPin);
  
  if (leftDistance > 0 && leftDistance < obstacleThreshold) {
    turnServoRelative(10);
  }
  
  if (rightDistance > 0 && rightDistance < obstacleThreshold) {
    turnServoRelative(10);
  }
}

void turnServoRelative(int degrees) {
  int targetPosition = currentServoPosition + degrees;
  if (targetPosition > 180) targetPosition = 180;
  if (targetPosition < 0) targetPosition = 0;

  myServo.write(targetPosition);
  delay(500); // small pause for movement

  // Move back by the same amount
  myServo.write(currentServoPosition);
  delay(500); // small pause for return

  // Keep servo position updated
  currentServoPosition = myServo.read();
}

void moveCar(int speed, bool forward, int duration_ms) {
  unsigned long startTime = millis();
  
  if (forward) {
    digitalWrite(motorPin1, HIGH);
    digitalWrite(motorPin2, LOW);
  } else {
    digitalWrite(motorPin1, LOW);
    digitalWrite(motorPin2, HIGH);
  }
  analogWrite(enablePin, speed);

  // Non-blocking wait
  while (millis() - startTime < (unsigned long)duration_ms) {
    if (Serial.available() > 0) {
      char c = Serial.read();
      executeCommand(c);
    }
  }
  analogWrite(enablePin, 0);
}

void parallelPark() {
  Serial.println("Starting parallel parking");

  myServo.write(90); 
  moveCar(200, true, 500);

  myServo.write(60); 
  moveCar(200, false, 144);

  myServo.write(90); 
  moveCar(200, true, 100);

  Serial.println("Parking complete");
}

void executeCommand(char command) {
  switch (command) {
    case 'R':
      turnServoRelative(50);
      break;
    case 'G':
      turnServoRelative(-50);
      break;
    case 'C':
      turnServoRelative(30);
      break;
    case 'A':
      turnServoRelative(-30);
      break;
    case 'P':
      parallelPark();
      break;
    default:
      break;
  }
}

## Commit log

2025-08-20 Rename Arduino_Code_Final.ino to Team Codes/Arduino Codes/Arduino_Code_Final.ino
2025-09-05 Create Materials
